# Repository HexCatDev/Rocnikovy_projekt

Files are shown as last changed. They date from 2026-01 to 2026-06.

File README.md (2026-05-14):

# Ročníkový projekt S3E Dobeš Tomáš Digitální hodiny
## Zvláštní poděkování
Zvláště bych chtěl poděkovat panu Miroslavu Máchovi za rady a pomoc při výběru součástek a řešení problémů konstrukčního typu.
A také  panu Jiřímu Vinterovi za rady a kontakty.

## To-do list
- [x] Navrhnout schéma 
- [x] Objednat součástky
- [x] Otestovat na breadboardu
- [x] Navrhnout PCB
- [x] Vyrobit PCB osadit, otestovat

## Princip a popis
Původní myšlenka jak zhotovit tento obvod byla, že by se jednotlivé výstupy na zobrazovače připojily přes posuvné registry, ovšem bylo by jich zapotřebí 6 kousků (HH:mm:ss) převod časového údaje z RTC by bylo zhotoveno přímo v PIC.

Po konzultaci s panem Máchou by bylo lepší Multiplexovat číslice 1:6 tzn. že v jednom okamžiku problikne jeden segment, takto se "probliká" každý segment zvlášť v určité rychlosti(Hz), od určité rychlosti ± 30 Hz se obraz jeví jako spojitý.[1]
### Blokové schéma

<figure>
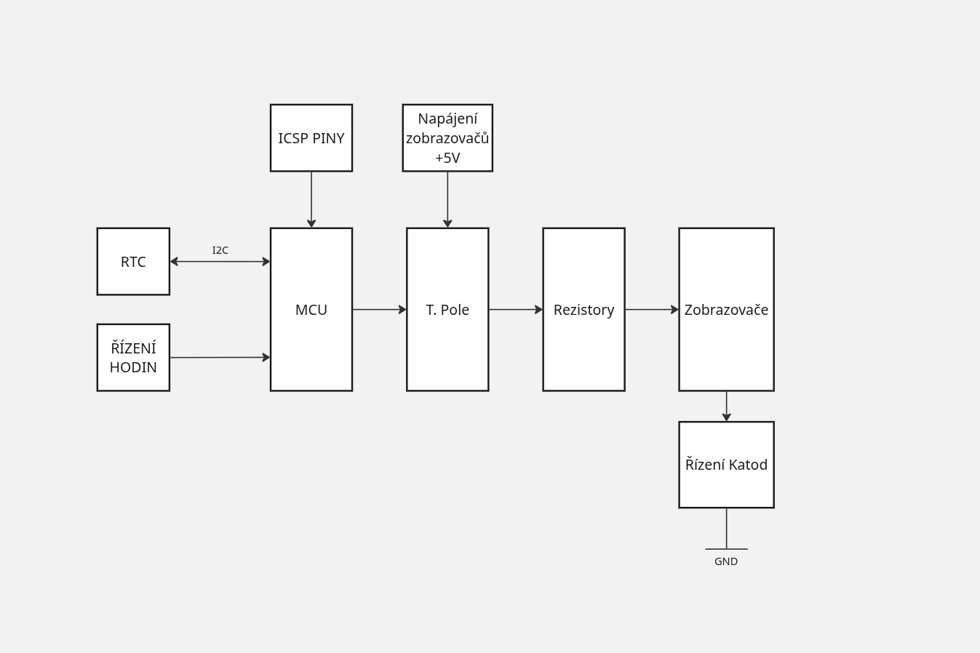
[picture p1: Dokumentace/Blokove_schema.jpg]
Blokové schéma
  
  <figcaption align="center"><i>Obrázek 1: Blokové schéma zapojení hodin</i></figcaption>
</figure>

### Součástky a jejich funkce v obvodu
V této podkapitole budou popsány hlavně podstatné součástky RTC, PIC, tranzistorové pole a samotné tranzistory (touto částí obvodu se chápe zobrazovací část. Vzhledem ke složitosti projektu zde nebude popsáno jak každý samostatný prvek funguje. 

- Obecné informace na vstupu napětí jsou  umístěny tzv. Tank Capacitors[2, kap. 4.2.2], jsou to dva kondenzátory 100uF/35V na napájení jejich funkce zajišťuje stabilní napětí při náhlém zvětšení proudového zatížení. Každý IO napájený z VCC má připojený tzv. Decoupling Capacitors[10] tyto kondenzátory mají na starosti odrušení od možných na indukovaných vysokých frekvencí, všechny mají hodnotu 100nF. Dále je v obvodu implementována dioda která obvod chrání před přepólováním její úbytek je ± 1100mV[11], takže velikost napájecího napětí bude 6V (6-1 = 5V) maximální napětí všech IO je 5,5V. Před vyrobením PCB bude zdroj otestován na stabilitu napětí.

- Mozkem obvodu je PIC18F47Q43-I-P[2] má na starosti komunikaci s RTC, multiplexování a řízení hodin. 

- RTC (Real Time Clock)[3] a Krystal[4] 
Tento IO komunikuje pomocí I2C protokolu s PIC a poskytuje časový údaj tento údaj je poskytován v dekadickém formátu. Má také externí zdroj oscilací krystal o frekvenci 32 768 Hz tato hodnota je definovaná v jeho dokumentaci[3, kap. 4.2.1]. Doporučená hodnota kondenzátorů které slouží jako kapacitní zátěž je 20pF.[3, kap. 4.2.1] Kondenzáty byly zapojeny podle doporučeného zapojení v citaci 3 kapitole FIGURE 4-3[3, kap. FIGURE 4-3].

- Tranzistorové pole ULN2804A[5] tento IO ve svém pouzdře DIP 18 obsahuje 8x NPN transistorů se spol. emitorem s max. kolektorovím  proudem 0,5A a max. napětím mezi kolektorem a emitorem 50V tento IO slouží pro výběr segmentu který bude svítit (A-DP)

- 7 Segmentové zobrazovače[6][7] 2x 20,32mm a 2x 10mm se společnou katodou obsahují 16x znaků v pouzdře 2x8 (7+DP) jsou připojeny na přes rezistory na ULN2804A[5] a jednotlivé znaky jsou připojeny přes tranzistory DTA123JCA[8] které uzemňují daný znak.

- tranzistory IRLML5203 SMD[8] P-MOSFET Uds max. 30V Ic 3A P 1.25W tyto tranzistory zajišťují spojení daného segmentu s napětím VCC tzn. pokud bude na 1. digitu svítit znak "A" ULN2804A[5] přivede na pin A napětí a poté tranzistor sepne a tím přivede na anodu proud poteče přes segmenty které jsou uzemněné a v důsledku toho se rozsvítí.

Video: https://youtu.be/Hi3HrBMFoAA

## Návrh schéma a PCB
- návrh schéma byl konzultován s panem Máchou a také byl upravován v souladu s dokumentací jednotlivých součástek s jejich doporučeními.

<figure>
Schéma strana hlavní
  
  <figcaption align="center"><i>Obr. 1.: Schéma zapojení</i></figcaption>
</figure>

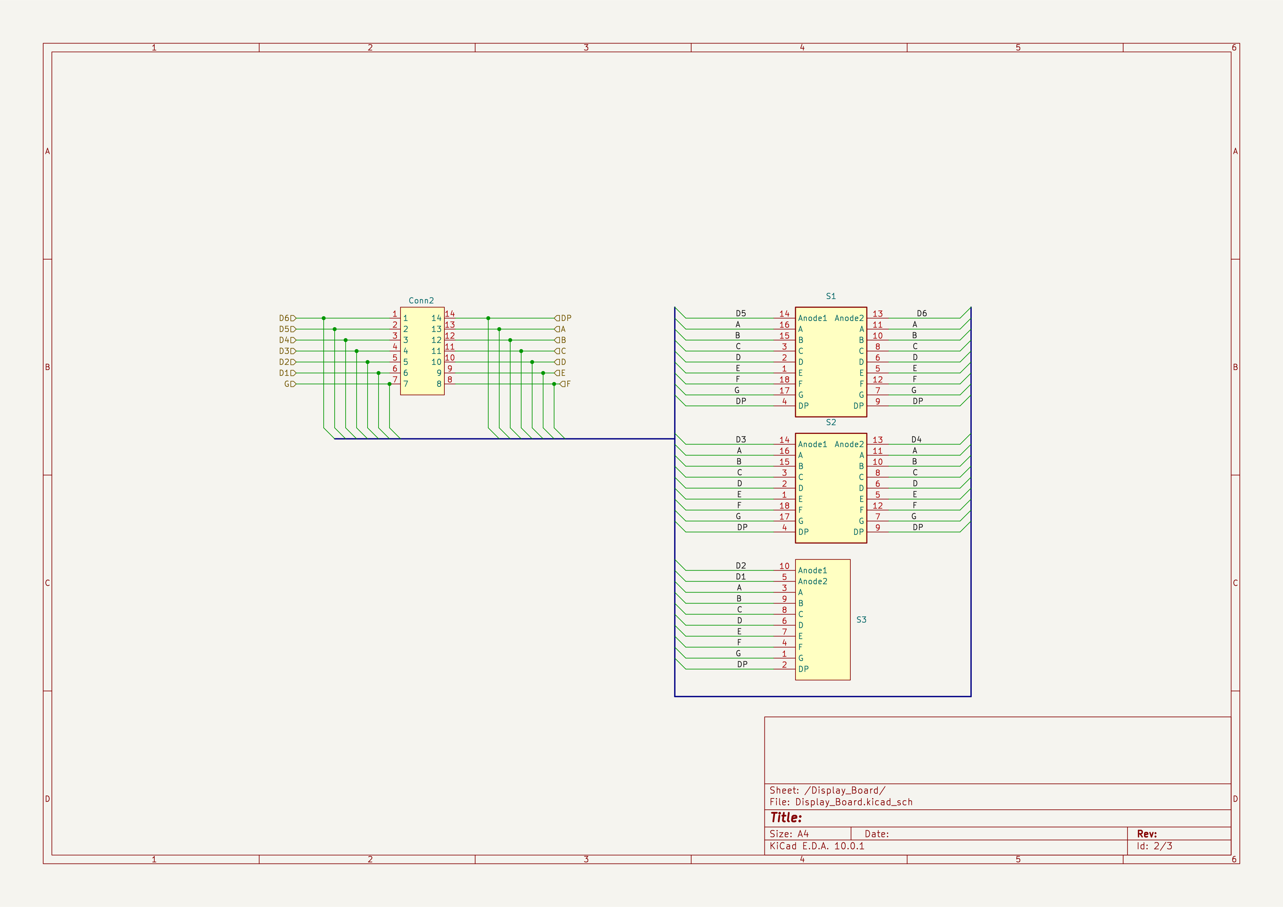
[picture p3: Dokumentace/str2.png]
  
  <figcaption align="center"><i>Obr. 2: Schéma zapojení</i></figcaption>
</figure>

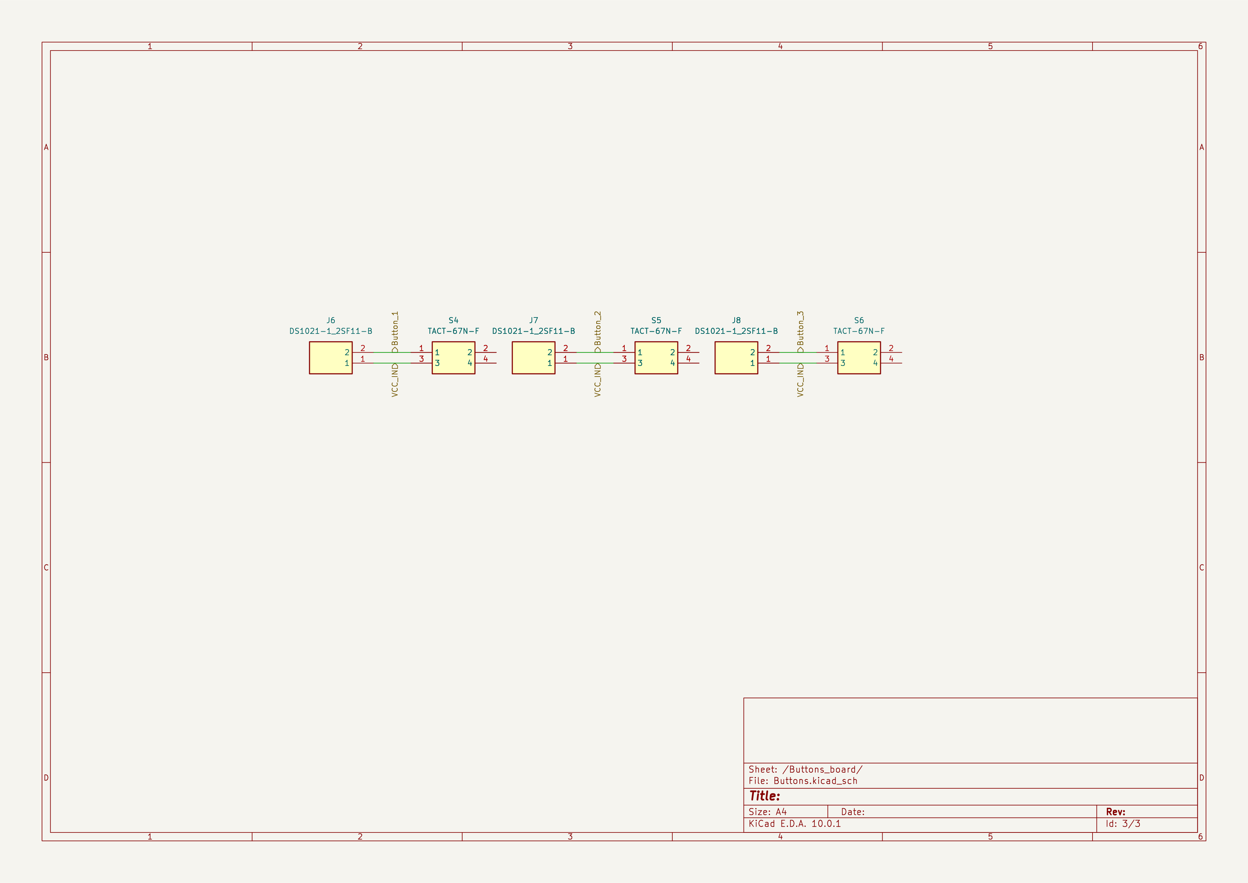
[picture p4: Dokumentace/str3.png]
  
  <figcaption align="center"><i>Obr. 3: Schéma zapojení</i></figcaption>
</figure>

<figure>
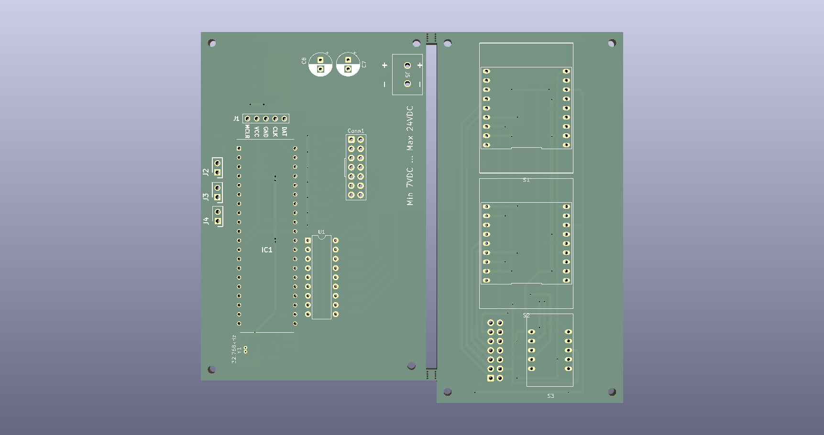
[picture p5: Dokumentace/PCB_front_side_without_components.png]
  
  <figcaption align="center"><i>Obr. 5: Neosazená PCB deska z horní strany strany</i></figcaption>
</figure>

<figure>
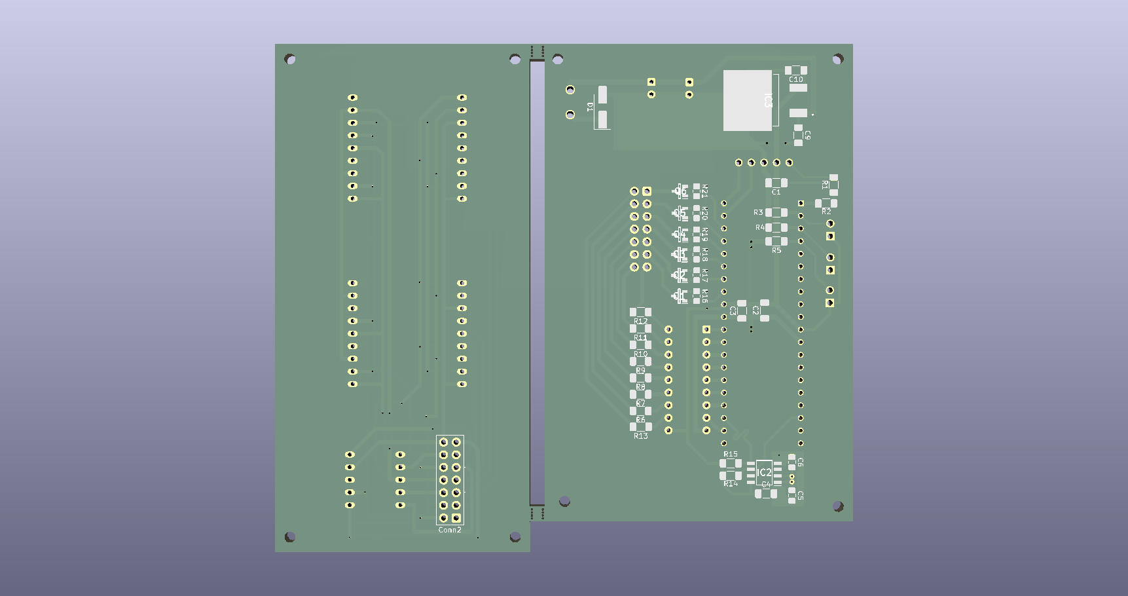
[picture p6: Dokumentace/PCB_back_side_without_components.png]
  
  <figcaption align="center"><i>Obrázek 7: Neosazená PCB deska ze spodní strany</i></figcaption>
</figure>

## Komponenty použité v projektu
- Aktivní součástky
	+ MCU https://ecom.cz/eshop/detail/73426-PIC18F47Q43-I-P
	+ RTC https://ecom.cz/eshop/detail/39997-MCP7940M-I-SN
	+ T. pole https://ecom.cz/eshop/detail/5723-ULN2804A
	+ Tranzistory SMD https://ecom.cz/eshop/detail/80941
	+ Dioda SMD https://ecom.cz/eshop/detail/82063-M7-SMD-T-R
- Krystal
	+ Crystal https://www.tme.eu/cz/details/32.768k-38-sr/krystalove-rezonatory-tht/sr-passives/32-768k-3-8-sr/
- Headry:
	+ 2X https://ecom.cz/eshop/detail/84648
	+ 5X https://ecom.cz/eshop/detail/84654
- Patice
	+ SIL 1X5 https://ecom.cz/eshop/detail/85256
  + SIL 1X9 https://ecom.cz/eshop/detail/85261
  + DIP 18 https://ecom.cz/eshop/detail/64634-DIL-18-3-NT-1
  + DIP 40 https://ecom.cz/eshop/detail/64639-DIL-40-6-YT-1
- Zobrazovače
	+ 7 segment 2X 20,32mm: https://ecom.cz/eshop/detail/29807-LD-FYD-8021DUHR-21
	+ 7 segment 10mm: https://ecom.cz/eshop/detail/29798-LD-FYD-3921BUHR-21
- Pasivní součástky
	+ Rezistory a Kondenzátory
		* 4K7 https://ecom.cz/eshop/detail/71624-R1206-4K7-1--WRX
		* 22 pF https://ecom.cz/eshop/detail/53662
		* 100 nF https://ecom.cz/eshop/detail/21330-C1206-0-1UF-X7R-100V-KNCC
		* 470R https://ecom.cz/eshop/detail/71620-R1206-470R-1--WRX
		* 100uF/35V https://ecom.cz/eshop/detail/78716-CERA-100-35-6-3x11-KM
		* 220R https://ecom.cz/eshop/detail/71588
- Svorkovnice https://ecom.cz/eshop/detail/6649-DG126-5-0-02P-14-02
- Tlačítka https://ecom.cz/eshop/detail/55539-T-0670HIM-160G
- Napájecí vidlice (zásuvka) https://ecom.cz/eshop/detail/78223-KNAPZP-25-1610-01
	+ zástrčka https://ecom.cz/eshop/detail/78201-KNAPVK-2514-NES-J-250
## Použitá literatura

- [1] WIKIPEDIA CONTRIBUTORS. *Flicker fusion threshold*. Wikipedia: The Free Encyclopedia [online]. [cit. 2026-01-02]. Dostupné z: https://en.wikipedia.org/wiki/Flicker_fusion_threshold
- [2] MICROCHIP TECHNOLOGY. *PIC18F27/47/57Q43 Data Sheet: 28/40/44/48-Pin, Low-Power, High-Performance Microcontroller with XLP Technology*. 2021. Dostupné z: https://ecom.cz/data/exportdokumentu?soubor=D73426.pdf&nazev=ECOM_73426_PIC18F47Q43-I-P.pdf 
- [3] MICROCHIP TECHNOLOGY. *MCP7940M: Low-Power I2C Real-Time Clock/Calendar with SRAM*. 2012. Dostupné z: https://ecom.cz/data/exportdokumentu?soubor=D39997.pdf&nazev=ECOM_39997_MCP7940M-I-SN.pdf
- [4] SR PASSIVES. *Crystal 32.768kHz: 32.768K-3/8-SR Specification*. Dostupné z: https://www.tme.eu/Document/4ebb629a31bbf93152d2908870dbe0d1/WX2.pdf
- [5] STMICROELECTRONICS. *ULN2801A, ULN2802A, ULN2803A, ULN2804A: Eight Darlington Transistor Arrays*. 2012. Dostupné z: https://ecom.cz/data/exportdokumentu?soubor=D05723.pdf&nazev=ECOM_05723_ULN2804A.pdf
- [6] FORYARD OPTOELECTRONICS. *FYD-8021DUHR-21: Dual Digit 7-Segment Display Specification*. Dostupné z: https://ecom.cz/data/exportdokumentu?soubor=D29806.pdf&nazev=ECOM_29807_LD-FYD-8021DUHR-21.pdf
- [7] FORYARD OPTOELECTRONICS. *FYD-3921BUHR-21: Single Digit 7-Segment Display Specification*. Dostupné z:https://ecom.cz/data/exportdokumentu?soubor=D29797.pdf&nazev=ECOM_29798_LD-FYD-3921BUHR-21.pdf
- [8] 	IRF - Infineon/International Rectifier. *	Tranzistor MFET-P, Uds=30V, Id=3A, P=1.25W, Ron=165mOhm*. Dostupné z: https://ecom.cz/data/exportdokumentu?soubor=D80941.pdf&nazev=ECOM_80941_IRLML5203-SMD.pdf
- [10] WIKIPEDIA CONTRIBUTORS. *Decoupling*. Wikipedia: The Free Encyclopedia [online]. Dostupné z: https://en.wikipedia.org/wiki/Capacitor#Decoupling
- [11] KOME *M7 SMD T/R* Dostupné z: https://www.tme.eu/Document/4a413fd76a83438d5e8f54eb6b2d20d6/m1.pdf

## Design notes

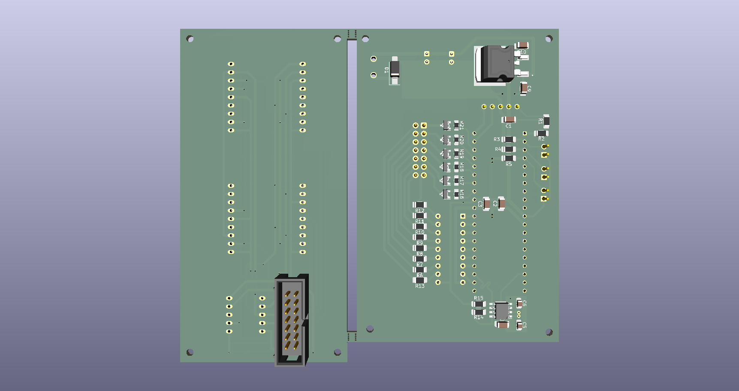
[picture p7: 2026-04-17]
Dokumentace/PCB_back_side.png

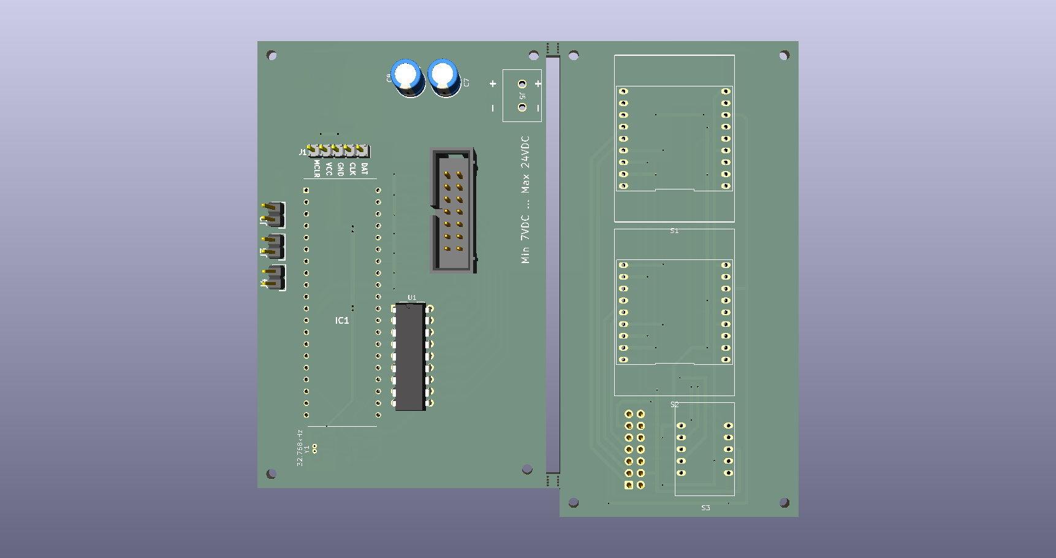
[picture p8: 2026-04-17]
Dokumentace/PCB_front_side.png

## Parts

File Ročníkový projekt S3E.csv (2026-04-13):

Reference | Qty | Value | Footprint
C1,C2 | 2 | 100uF | Capacitor_THT:CP_Radial_D6.3mm_P2.50mm
C3,C4,C5,C6,C7,C10 | 6 | 100nF | Capacitor_SMD:C_1206_3216Metric_Pad1.33x1.80mm_HandSolder
C8,C9 | 2 | 7pF | Capacitor_SMD:C_0805_2012Metric_Pad1.18x1.45mm_HandSolder
Conn1,Conn2 | 2 | ~ | My parts:DIP-14_IDC_2x14
D1 | 1 | M7 SMD T/R | Diode_SMD:D_SMA_Handsoldering
IC1 | 1 | PIC18F47Q43-I_P | My parts:DIP1543W58P254L5175H635Q40N
IC2 | 1 | ULN2804A | My parts:DIP850W46P254L2324H393Q18N
IC3 | 1 | L7805CD2T-TR | My parts:L7805CD2T
IC4 | 1 | MCP7940M-I_SN | SOIC127P600X175-8N
J1 | 1 | DG126-5.0-02P-14-00A | My parts:CONN_DG126-5.0-02P_DEG
J2,J3,J5 | 3 | DS1021-1_2SF11-B | SamacSys_Parts:HDRV2W64P0X254_1X2_508X254X588P
J4 | 1 | TSW-105-07-G-S | My parts:TSW-105-XX-YY-S
J6,J7,J8 | 3 | DS1021-1_2SF11-B | HDRV2W64P0X254_1X2_508X254X588P
Q1,Q2,Q3,Q4,Q5,Q6 | 6 | DTA123JCAT116 | My parts:TRANS_DTA113ZCAH_ROM
R1,R2,R3,R4,R5,R6,R7,R8 | 8 | 330R | Resistor_THT:R_Axial_DIN0309_L9.0mm_D3.2mm_P12.70mm_Horizontal
R9,R11,R12,R13,R14 | 5 | 4K7 | Resistor_SMD:R_1206_3216Metric_Pad1.30x1.75mm_HandSolder
R10 | 1 | 470R | Resistor_SMD:R_1206_3216Metric_Pad1.30x1.75mm_HandSolder
R15 | 1 | 4k7 | Resistor_SMD:R_1206_3216Metric_Pad1.30x1.75mm_HandSolder
S1 | 1 | S,TACT-67N-F | My parts:Patice_display,TACT67NF
S2,S3 | 2 | TACT-67N-F | TACT67NF
Y1 | 1 | 32 768Hz | Crystal:32.768KHz Vertical 3_8mm

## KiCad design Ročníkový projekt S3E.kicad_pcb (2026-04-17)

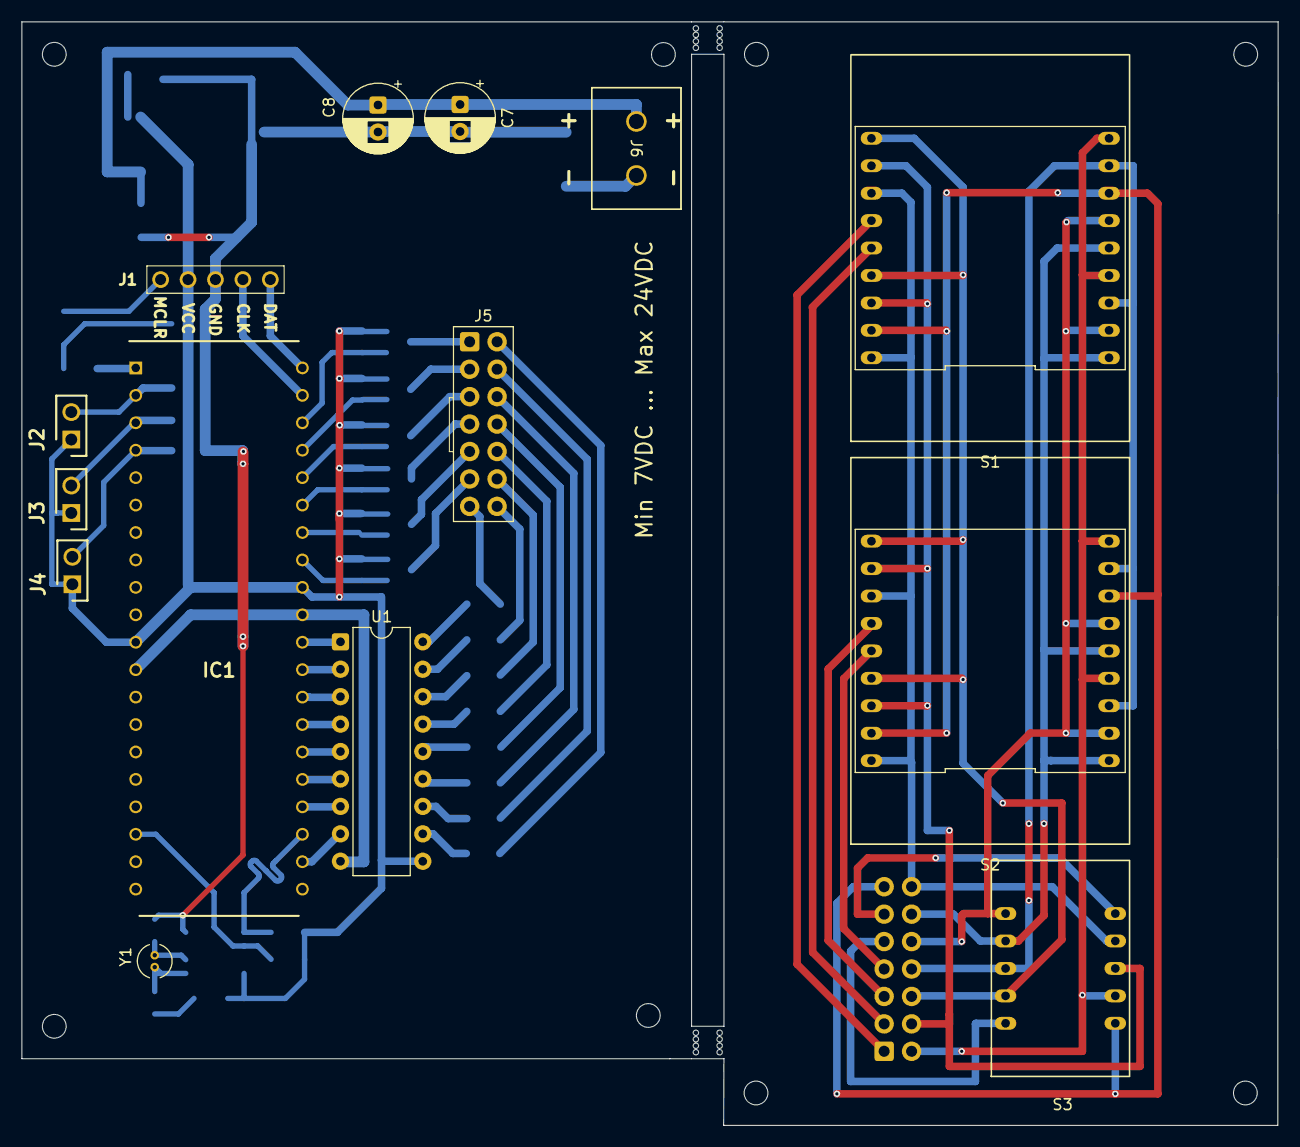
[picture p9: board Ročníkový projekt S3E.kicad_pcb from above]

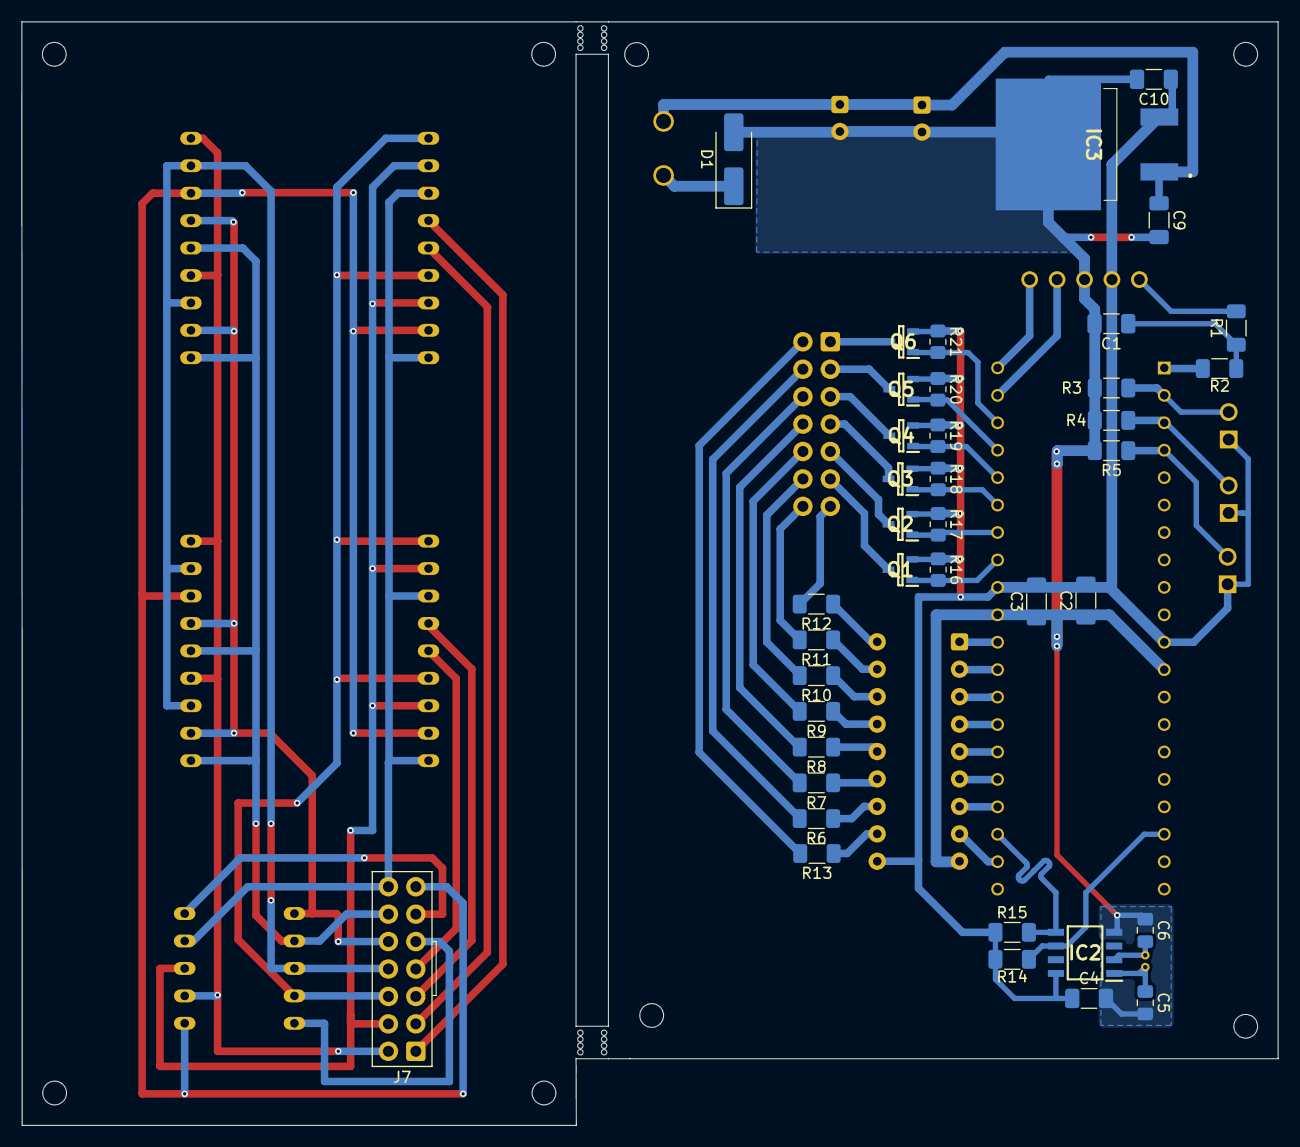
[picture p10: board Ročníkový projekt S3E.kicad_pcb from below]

Board: 2 copper layers, 116.3 x 102.2 mm, 59 parts (39 on the bottom side), 52 nets.

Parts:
C1, C2, C3, C4, C9, C10: 100nF; C_1206_3216Metric_Pad1.33x1.80mm_HandSolder
C5, C6: 6,8pF; C_0805_2012Metric_Pad1.18x1.45mm_HandSolder
C7, C8: 100uF; CP_Radial_D6.3mm_P2.50mm
D1: M7 SMD T/R; D_SMA_Handsoldering
H1, H2, H3, H4, H5, H6: MountingHole_2.2mm_M2
IC1: PIC18F47Q43-I_P; DIP1543W58P254L5175H635Q40N
IC2: MCP7940M-I_SN; SOIC127P600X175-8N
IC3: L7805CD2T-TR; L7805CD2T
J1: TSW-105-07-G-S; TSW-105-XX-YY-S
J2, J3, J4: DS1021-1_2SF11-B; HDRV2W64P0X254_1X2_508X254X588P
J5, J7: DIP-14_IDC_2x14
J6: DG126-5.0-02P-14-00A; CONN_DG126-5.0-02P_DEG
Q1, Q2, Q3, Q4, Q5, Q6: YJL2301D; SOT95P240X115-3N
R1, R3, R4, R5, R14, R15: 4K7; R_1206_3216Metric_Pad1.30x1.75mm_HandSolder
R2: 470R; R_1206_3216Metric_Pad1.30x1.75mm_HandSolder
R6, R7, R8, R9, R10, R11, R12, R13: 220R; R_1206_3216Metric_Pad1.30x1.75mm_HandSolder
R16, R17, R18, R19, R20, R21: 10K; R_0805_2012Metric_Pad1.20x1.40mm_HandSolder
S1, S2: DIP 18 Patice Display Digit 1
S3: DIP-10 Patice Display Digit 3 4
U1: ULN2803A; DIP-18_W7.62mm
Y1: 32 768Hz; Crystal_C38-LF_D3.0mm_L8.0mm_Vertical MY 32kHz

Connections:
/A: R6.1, U1.12 (O7)
/A': J5.13, J7.13, R6.2, S1.11 (A), S1.16 (A), S2.11 (A), S2.16 (A), S3.3 (A)
/B: R7.1, U1.13 (O6)
/B': J5.12, J7.12, R7.2, S1.10 (B), S1.15 (B), S2.10 (B), S2.15 (B), S3.9 (B)
/Buttons_board/Button_1: IC1.2 (RA0), J2.2, R3.1
/Buttons_board/Button_2: IC1.3 (RA1), J3.2, R4.1
/Buttons_board/Button_3: IC1.4 (RA2), J4.2, R5.1
/C: R8.1, U1.14 (O5)
/C': J5.11, J7.11, R8.2, S1.3 (C), S1.8 (C), S2.3 (C), S2.8 (C), S3.8 (C)
/D: R9.1, U1.15 (O4)
/D': J5.10, J7.10, R9.2, S1.2 (D), S1.6 (D), S2.2 (D), S2.6 (D), S3.6 (D)
/DP: R13.1, U1.11 (O8)
/DP': J5.14, J7.14, R13.2, S1.4 (DP), S1.9 (DP), S2.4 (DP), S2.9 (DP), S3.2 (DP)
/Display_Board/D1: J5.6, J7.6, Q1.3 (D), S3.5 (Anode2)
/Display_Board/D2: J5.5, J7.5, Q2.3 (D), S3.10 (Anode1)
/Display_Board/D3: J5.4, J7.4, Q3.3 (D), S2.14 (Anode1)
/Display_Board/D4: J5.3, J7.3, Q4.3 (D), S2.13 (Anode2)
/Display_Board/D5: J5.2, J7.2, Q5.3 (D), S1.14 (Anode1)
/Display_Board/D6: J5.1, J7.1, Q6.3 (D), S1.13 (Anode2)
/E: R10.1, U1.16 (O3)
/E': J5.9, J7.9, R10.2, S1.1 (E), S1.5 (E), S2.1 (E), S2.5 (E), S3.7 (E)
/F: R11.1, U1.17 (O2)
/F': J5.8, J7.8, R11.2, S1.12 (F), S1.18 (F), S2.12 (F), S2.18 (F), S3.4 (F)
/G: R12.1, U1.18 (O1)
/G': J5.7, J7.7, R12.2, S1.7 (G), S1.17 (G), S2.7 (G), S2.17 (G), S3.1 (G)
A_1: IC1.33 (RB0), Q1.1 (G), R16.2
A_2: IC1.34 (RB1), Q2.1 (G), R17.2
A_3: IC1.35 (RB2), Q3.1 (G), R18.2
A_4: IC1.36 (RB3), Q4.1 (G), R19.2
A_5: IC1.37 (RB4), Q5.1 (G), R20.2
A_6: IC1.38 (RB5), Q6.1 (G), R21.2
GND: C1.2, C2.1, C3.1, C4.2, C5.2, C6.1, C7.2, C8.2, C9.2, C10.2, D1.2 (A), IC1.12 (VSS_1), IC1.31 (VSS_2), IC2.4 (VSS), IC3.2 (GND), J1.3, R3.2, R4.2, R5.2, U1.9 (GND)
ICSP_CLK: IC1.39 (RB6/ICSPCLK), J1.4
ICSP_DAT: IC1.40 (RB7/ICSPDAT), J1.5
unnamed: C1.1, R1.1, R2.2
unnamed: D1.1 (K), J6.2
unnamed: IC1.1 (~MCLR/VPP/RE3), R2.1
unnamed: C5.1, IC2.1 (X1), Y1.1
unnamed: C6.2, IC2.2 (X2), Y1.2
unnamed: C7.1, C8.1, C9.1, IC3.1 (INPUT), J6.1
unnamed: J1.1, R1.2
PIC_A: IC1.24 (RC5), U1.7 (I7)
PIC_B: IC1.25 (RC6), U1.6 (I6)
PIC_C: IC1.26 (RC7), U1.5 (I5)
PIC_D: IC1.27 (RD4), U1.4 (I4)
PIC_DP: IC1.22 (RD3), U1.8 (I8)
PIC_E: IC1.28 (RD5), U1.3 (I3)
PIC_F: IC1.29 (RD6), U1.2 (I2)
PIC_G: IC1.30 (RD7), U1.1 (I1)
SCL: IC1.18 (RC3), IC2.6 (SCL), R14.2
SDA: IC1.23 (RC4), IC2.5 (SDA), R15.2
VCC: C2.2, C3.2, C4.1, C10.1, IC1.11 (VDD_1), IC1.32 (VDD_2), IC2.8 (VCC), IC3.3 (OUTPUT), J1.2, J2.1, J3.1, J4.1, Q1.2 (S), Q2.2 (S), Q3.2 (S), Q4.2 (S), Q5.2 (S), Q6.2 (S), R14.1, R15.1, R16.1, R17.1, R18.1, R19.1, R20.1, R21.1, U1.10 (COM)

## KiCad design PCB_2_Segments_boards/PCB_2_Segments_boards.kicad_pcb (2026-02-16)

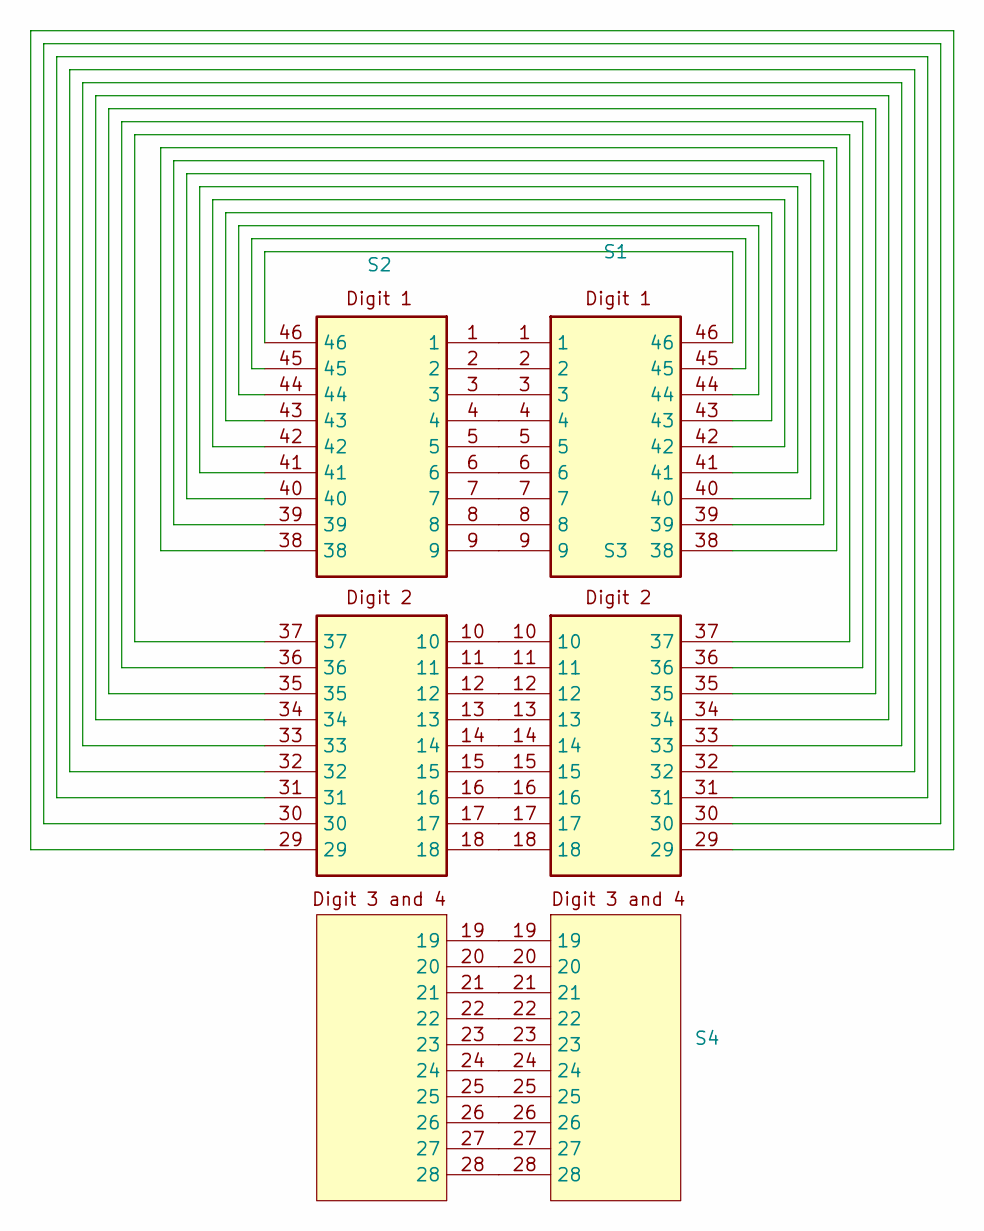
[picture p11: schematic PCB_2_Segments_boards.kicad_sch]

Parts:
S1: DIP 18 Patice Display Digit 1
S2: S; Patice_display
S3: DIP 18 Patice Display Digit 2
S4: DIP-10 Patice Display Digit 3 4

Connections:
unnamed: S1.1, S2.1
unnamed: S1.2, S2.2
unnamed: S1.3, S2.3
unnamed: S1.4, S2.4
unnamed: S1.5, S2.5
unnamed: S1.6, S2.6
unnamed: S1.7, S2.7
unnamed: S1.8, S2.8
unnamed: S1.9, S2.9
unnamed: S1.38, S2.38
unnamed: S1.39, S2.39
unnamed: S1.40, S2.40
unnamed: S1.41, S2.41
unnamed: S1.42, S2.42
unnamed: S1.43, S2.43
unnamed: S1.44, S2.44
unnamed: S1.45, S2.45
unnamed: S1.46, S2.46
unnamed: S2.10, S3.10
unnamed: S2.11, S3.11
unnamed: S2.12, S3.12
unnamed: S2.13, S3.13
unnamed: S2.14, S3.14
unnamed: S2.15, S3.15
unnamed: S2.16, S3.16
unnamed: S2.17, S3.17
unnamed: S2.18, S3.18
unnamed: S2.19, S4.19
unnamed: S2.20, S4.20
unnamed: S2.21, S4.21
unnamed: S2.22, S4.22
unnamed: S2.23, S4.23
unnamed: S2.24, S4.24
unnamed: S2.25, S4.25
unnamed: S2.26, S4.26
unnamed: S2.27, S4.27
unnamed: S2.28, S4.28
unnamed: S2.29, S3.29
unnamed: S2.30, S3.30
unnamed: S2.31, S3.31
unnamed: S2.32, S3.32
unnamed: S2.33, S3.33
unnamed: S2.34, S3.34
unnamed: S2.35, S3.35
unnamed: S2.36, S3.36
unnamed: S2.37, S3.37

Board: 2 copper layers, 4 parts (0 on the bottom side), 46 nets, no tracks yet.

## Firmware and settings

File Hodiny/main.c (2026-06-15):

/**
 * @file main.c
 * @author nontoxiccat
 * @date 2026-01-08
 * @brief 
 */
#include "My_MCC_Config/mcc/mcc_generated_files/system/interrupt.h"
#include <builtins.h>
#include <stdbool.h>
#include <stdint.h>
#include <string.h>
#include <xc.h>
#include <pic18f47q43.h>
// Configuration bits for PIC18F47Q43
#pragma config WDTE = OFF              // Watchdog Timer disabled
#pragma config LVP = ON

#define _XTAL_FREQ 64000000 // Define the operating frequency for delay functions
#define RTC_ADDR 0x6F    // adress 7 bit 110 1111 
#define SEC_REG 0x00        // seconds register
#define MIN_REG 0X01        // minutes register
#define HOUR_REG 0X02       // hours register
#define TL_SET PORTAbits.RA1 // tlačítko pro nastavení pozice
#define TL_ADD PORTAbits.RA2 // tlačítko pro přidání hodin
#define TL_SUB PORTAbits.RA0 // tlačítko pro odečtení hodin

#include "My_MCC_Config/mcc/mcc_generated_files/timer/tmr0.h"
#include "My_MCC_Config/mcc/mcc_generated_files/system/system.h"
#include "My_MCC_Config/mcc/mcc_generated_files/i2c_host/i2c1.h"
#include "clock_config.h" //můj soubor jsou v něm definovány segmenty pro zobrazení číslic a funkce pro zobrazení číslice a nastavení hodin



int main(void)
{ 
    SYSTEM_Initialize();  // this is enough
    pin_init();
    I2C1_Host_CallbackRegister(My_I2C1_Interrupt);
    TMR0_OverflowCallbackRegister(timer);
    TMR0_Start();
    INTCON0bits.GIEH = 1; 
    INTCON0bits.GIEL = 1;

    
    while (1) {
        if (in_setup_mode == 0) {
            if (sys_clock) {
                system_clock();
                sys_clock = false;
            }
            if (RTC_sync) {
                READ_RTC();
                RTC_sync = false;
            }
            if (waiting_for_data && I2C_trasmission_complete) {
                process_data_from_RTC();
                waiting_for_data = false;
            }
        }
        display_controll();
    }
}

void display_digit(const uint8_t *segments){
    // Indexy v poli: 0=DP, 1=G, 2=F, 3=E, 4=D, 5=C, 6=B, 7=A
    LATDbits.LATD3 = segments[0] & 0x1; // DP
    LATDbits.LATD7 = segments[1] & 0x1; // G
    LATDbits.LATD6 = segments[2] & 0x1; // F
    LATDbits.LATD5 = segments[3] & 0x1; // E
    LATDbits.LATD4 = segments[4] & 0x1; // D
    LATCbits.LATC7 = segments[5] & 0x1; // C
    LATCbits.LATC6 = segments[6] & 0x1; // B
    LATCbits.LATC5 = segments[7] & 0x1; // A
}

void clock_init(uint8_t numbers_out[6]) {
    in_setup_mode = 1; // nastaví se, že jsme v režimu nastavení hodin
    int selected_digit = 4;
    int hold_button_time = 0, theshold = 500; // proměnné pro detekci dlouhého stisku tlačítka, threshold je počet 10ms intervalů pro detekci dlouhého stisku
    int timeout = 0; // proměnná pro detekci timeoutu při čekání na dokončení I2C přenosu, aby se zabránilo nekonečnému čekání pokud by došlo k nějaké chybě v komunikaci s RTC
    int threshold = 333;
    while (1) {
        if (TL_SET == 1) {
            hold_button_time++;
            if (hold_button_time > theshold) {
                // tady se odešlou hodnoty z numbers out do RTC přes I2C a zapnase oscilátor
                I2C_trasmission_complete = false; //reset flagu pro indikaci dokončení I2C přenosu, protože jsme právě zahájili nový přenos
                WRITE_RTC(); //tato funkce se bude volat při dlouhém stisku tlačítka pro nastavení hodin a odešle hodnoty z numbers_out do RTC
                while (!I2C_trasmission_complete && timeout < 100) { //čeká se na uvolnění tlačítka nebo dokončení I2C přenosu, aby se zabránilo tomu, že se během přenosu změní nastavené hodnoty nebo se odešle neúplný přenos
                    __delay_ms(10);
                    timeout++;
                    LATB |= 0x3F; //nastaví všechny tranzistory na high takže se vypnou protože PNP display zhasne
                }
            in_setup_mode = 0; // po uvolnění tlačítka se vypne režim nastavení hodin
            __delay_ms(100);
            TMR0_Start(); // znovu se spustí časovač aby se začal aktualizovat čas na displeji
            return; // po uvolnění tlačítka se vrátí do hlavní smyčky a začne zobrazovat čas
            }
        
        }
        else {
            // Ochrana proti zákmitům (debouncing): tlačítko muselo být stisknuto alespoň 15 průchodů (cca 45 ms)
        if (hold_button_time > 15 && hold_button_time < theshold) { 
            selected_digit = (selected_digit + 1) % 6; // přepnutí na další číslici
        }
            hold_button_time = 0; // reset času držení tlačítka
        }

        if (TL_SUB == 1) {
            switch (selected_digit) {
                case 0: numbers_out[0] = (numbers_out[0] >= 2) ? 0 : numbers_out[0] + 1; break; //hh 0,1,2
                case 1: numbers_out[1] = (numbers_out[1] >= 9) ? 0 : numbers_out[1] + 1; break; //h 0-9
                case 2: numbers_out[2] = (numbers_out[2] >= 5) ? 0 : numbers_out[2] + 1; break; //mm 0-5
                case 3: numbers_out[3] = (numbers_out[3] >= 9) ? 0 : numbers_out[3] + 1; break; //m 0-9
                case 4: numbers_out[4] = (numbers_out[4] >= 5) ? 0 : numbers_out[4] + 1; break; //ss 0-6
                case 5: numbers_out[5] = (numbers_out[5] >= 9) ? 0 : numbers_out[5] + 1; break; //s 0-9
            }
            for (int d = 0; d < 100; d++) {
                refresh_setup_display(selected_digit, numbers_out);
            }
        }

        if (TL_ADD == 1) {
            switch (selected_digit) {
                //tady jsem použil ternary operace tj. (kondice) ? (je pravda) : (není pravda) protože když odečítám 1 od 0, chci aby se číslo změnilo na maximum (např. pro minuty když je 00 a odečtu 1, chci aby se změnilo na 59)
                case 0: numbers_out[0] = (numbers_out[0] -1 ) < 0 ? 2 : numbers_out[0] - 1; break; //hh 0,1,2
                case 1: numbers_out[1] = (numbers_out[1] -1 ) < 0 ? 9 : numbers_out[1] - 1; break; //h 0-9
                case 2: numbers_out[2] = (numbers_out[2] -1 ) < 0 ? 5 : numbers_out[2] - 1; break; //mm 0-5
                case 3: numbers_out[3] = (numbers_out[3] -1 ) < 0 ? 9 : numbers_out[3] - 1; break; //m 0-9
                case 4: numbers_out[4] = (numbers_out[4] -1 ) < 0 ? 5 : numbers_out[4] - 1; break; //ss 0-6
                case 5: numbers_out[5] = (numbers_out[5] -1 ) < 0 ? 9 : numbers_out[5] - 1; break; //s 0-9
            }
            for (int d = 0; d < 100; d++) {
                refresh_setup_display(selected_digit, numbers_out);
            }
        }

        if (numbers_out[0] == 2 && numbers_out[1] >= 4) { // pokud jsou hodiny nastaveny na 24 nebo více, resetuje se na 00
            numbers_out[0] = 0;
            numbers_out[1] = 0;
        }
        refresh_setup_display(selected_digit, numbers_out);
    }
}

void refresh_setup_display(int selected_digit, uint8_t numbers_out[6]) {
    for (int i = 0; i < 6; i++) {
        LATB |= 0x3F; // vypnutí všech tranzistorů (PNP displej zhasne)

        // Pokud index odpovídá vybrané pozici (selected_digit), použijeme znak s tečkou, jinak běžný znak
        const uint8_t *current_segments = (i == selected_digit) ? numbers_DP[numbers_out[i]] : numbers[numbers_out[i]];

        // Spínání tranzistorů podle aktuálního indexu 'i'
        switch (i) {
            case 0: display_digit(current_segments); LATBbits.LATB2 = 0; __delay_us(500); break; 
            case 1: display_digit(current_segments); LATBbits.LATB3 = 0; __delay_us(500); break; 
            case 2: display_digit(current_segments); LATBbits.LATB4 = 0; __delay_us(500); break; 
            case 3: display_digit(current_segments); LATBbits.LATB5 = 0; __delay_us(500); break; 
            case 4: display_digit(current_segments); LATBbits.LATB1 = 0; __delay_us(500); break; 
            case 5: display_digit(current_segments); LATBbits.LATB0 = 0; __delay_us(500); break; 
            default: break;
        }
    }
}

void display_controll(){
    if (TL_SET == 1) {
        TMR0_Stop(); //zastaví časovač aby se zabránilo konfliktu mezi timerem a zobrazením číslic při nastavení hodin
        ms_sync_counter = 0; //resetuje se čítač pro synchronizaci s RTC aby se zabránilo tomu, že se během nastavení hodin synchronizuje čas s RTC a změní se nám nastavené hodnoty
        ms_counter = 0; //resetuje se čítač pro synchronizaci s RTC aby se zabránilo tomu, že se během nastavení hodin synchronizuje čas s RTC a změní se nám nastavené hodnoty
        LATB |= 0x3F; //zhasne nám display
        __delay_ms(100);
        clock_init(numbers_out);
        __delay_ms(100);
    }

    for (int i = 0; i < 6; i++) {
        // toto je bitwisová operace OR pro nastavení bitů 0-5 na 1, což znamená, že všechny tranzistory jsou vypnuté (protože jsou PNP)
        LATB |= 0x3F;
        // nastaví určitý tranzistor na low takže se zapne
        switch (i) {
            case 0: display_digit(numbers[numbers_out[0]]); LATBbits.LATB2 = 0; __delay_us(500); break;
            case 1: display_digit(numbers[numbers_out[1]]); LATBbits.LATB3 = 0; __delay_us(500); break; 
            case 2: display_digit(numbers[numbers_out[2]]); LATBbits.LATB4 = 0; __delay_us(500); break; 
            case 3: display_digit(numbers[numbers_out[3]]); LATBbits.LATB5 = 0; __delay_us(500); break; 
            case 4: display_digit(numbers[numbers_out[4]]); LATBbits.LATB1 = 0; __delay_us(500); break; //s
            case 5: display_digit(numbers[numbers_out[5]]); LATBbits.LATB0 = 0; __delay_us(500); break; //ss
        }
    }
}

void READ_RTC(void) {
    waiting_for_data = true;
    I2C_trasmission_complete = false;
    static uint8_t reg_addr = SEC_REG;
    I2C1_Host_WriteRead(RTC_ADDR, &reg_addr, 1, bcd_numbers_recieved, 3); // "Host" prefix
}

void WRITE_RTC(){//tato funkce se bude volat při dlouhém stisku tlačítka pro nastavení hodin a odešle hodnoty z numbers_out do RTC

    payload[0] = SEC_REG; // adresa registru pro sekundy
    payload[1] = time_to_BCD(numbers_out[4], numbers_out[5]);
    payload[1] = payload[1] | 0x80; // bitwisový operátor OR (|) také funguje jako přenastavitel bitů nechá všechny bity stejné kromě bitu 7 který nastaví na 1 což zapne oscilátor v RTC
    payload[2] = time_to_BCD(numbers_out[2], numbers_out[3]); // hodnota pro minuty v BCD formátu
    payload[3] = time_to_BCD(numbers_out[0], numbers_out[1]); // hodnota pro hodiny v BCD formátu

    I2C_trasmission_complete = false;
    I2C1_Host_Write(RTC_ADDR, payload, 4); // odešle data do RTC, první byte je adresa registru pro sekundy a další 3 byty jsou hodnoty pro sekundy, minuty a hodiny v BCD formátu
}

void system_clock(){ //tato funkce se bude volat každou sekundu a bude aktualizovat čas na displeji a je založena na funkci timer()
    numbers_out[5]++; 
    if (numbers_out[5] >= 10) { 
        numbers_out[5] = 0;
        numbers_out[4]++;
        if (numbers_out[4] >= 6){ 
            numbers_out[4] = 0;
            numbers_out[3]++;
            if (numbers_out[3] >= 10){
                numbers_out[3] = 0;
                numbers_out[2]++;
                if (numbers_out[2] >= 6){ 
                    numbers_out[2] = 0;
                    numbers_out[1]++;
                    if (numbers_out[0] == 2 && numbers_out[1] >= 4) { 
                        memset(numbers_out, 0, sizeof(numbers_out));
                    } else if (numbers_out[1] >= 10) {
                        numbers_out[1] = 0;
                        numbers_out[0]++;
                    }
                }
            }
        }
    }
}

void timer(void){
    ms_sync_counter++; //inkrementace čítače pro měření času v milisekundách
    ms_counter++; //inkrementace čítače pro měření času v milisekundách
    if (ms_counter >= 997 && in_setup_mode == 0) { //když uplyne 1 sekunda
        sys_clock = true; //nastaví se flag pro sys clock
        ms_counter = 0;
    }
    if (in_setup_mode == 0) {
        if (ms_sync_counter >= 900000UL) { //když uplyne 15 minut, synchronizuje se čas s RTC
            RTC_sync = true; //nastaví se flag pro RTC sync
            ms_sync_counter = 0;
        }
    }
}

void My_I2C1_Interrupt(void){ // toto je callback funkce pro dokončení I2C přenosu, která se volá, když je I2C přenos dokončen
    I2C_trasmission_complete = true; //nastaví se flag pro indikaci dokončení I2C přenosu
}

void process_data_from_RTC(){ //tato funkce se bude volat, když je dokončen I2C přenos a aktualizuje čas na displeji podle dat z RTC
    bcd_numbers_recieved[0] = bcd_numbers_recieved[0] & 0x7F; //bitwisový operátor AND (&) nechá všechny bity stejné kromě bitu 7 který nastaví na 0 protože bit 7 v registru pro sekundy je pro oscilátor a nechceme ho zobrazovat na displeji
    numbers_out[4] = bcd_numbers_recieved[0] >> 4; //vyextrahuje desítky sekund z BCD hodnoty
    numbers_out[5] = bcd_numbers_recieved[0] & 0x0F; //vyextrahuje jednotky sekund z BCD hodnoty

    numbers_out[2] = bcd_numbers_recieved[1] >> 4; //vyextrahuje desítky minut z BCD hodnoty
    numbers_out[3] = bcd_numbers_recieved[1] & 0x0F; //vyextrahuje jednotky minut z BCD hodnoty
    
    bcd_numbers_recieved[2] = bcd_numbers_recieved[2] & 0x3F; //bitwisový operátor AND (&) nechá všechny bity stejné kromě bitů 6 a 7 které nastaví na 0 protože bity 6 a 7 v registru pro hodiny jsou pro 12/24 hodinový režim a AM/PM a nechceme je zobrazovat na displeji
    numbers_out[0] = bcd_numbers_recieved[2] >> 4; //vyextrahuje desítky hodin z BCD hodnoty
    numbers_out[1] = bcd_numbers_recieved[2] & 0x0F; //vyextrahuje jednotky hodin z BCD hodnoty
}

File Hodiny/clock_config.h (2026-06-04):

#ifndef CLOCK_CONFIG_H
#define CLOCK_CONFIG_H
#define _XTAL_FREQ 64000000 //definice frekvence pro delay funkce

#include <language_support.h>
#include <pic18f47q43.h>
#include <stdint.h>
#include <xc.h> 
#include <stdbool.h>

#define G = TRISDbits.TRISD7 = 0; //G
#define F = TRISDbits.TRISD6 = 0; //F
#define E = TRISDbits.TRISD5 = 0; //E
#define D = TRISDbits.TRISD4 = 0; //D
#define DP = TRISDbits.TRISD3 = 0; //DP
#define C = TRISCbits.TRISC7 = 0; //C
#define B = TRISCbits.TRISC6 = 0; //B
#define A = TRISCbits.TRISC5 = 0; //A

#define time_to_BCD(tens, ones) ( (uint8_t) ((tens) << 4) | (ones)) //toto je makro vloží se do něj dvě hodnoty desítky a jednotky a ono vrátí hodnotu
// v BCD formátu tj. pro třeba 45 sec máme 4 a 5, tens 4 ones 5 makro vezme 4 převede ho do binárního formátu což je 0100 a posune ji 
// o 4 bity doleva (<< 4) takže vznikne 0100 0000 pak je tu bitwise OR (|) což slepí dvě hodnoty doromady, 5 je v bin 0101 (4+1)
// výsledkem slepení je 0100 0101 což je 0x45 v hexu a to je BCD reprezentace čísla 45.
// takže tady to bude bcd_numbers[3] = {time_to_BCD(numbers_out[4], numbers_out[5])}
// do hodnoty 3 v poli bcd_numbers se uloží převod hodnot z numbers_out[4] a numbers_out[5] do BCD formátu což jsou sekundy
// to se pak jako celek pošle do RTC


// Forward declarations
void READ_RTC(void);
void WRITE_RTC(void);
void system_clock(void);
void timer(void);
void display_controll(void);
void My_I2C1_Interrupt(void);
void process_data_from_RTC(void);
void refresh_setup_display(int selected_digit, uint8_t numbers_out[6]);

const uint8_t numbers[10][8] = {
    {0, 0, 1, 1, 1, 1, 1, 1}, //0
    {0, 0, 0, 0, 0, 1, 1, 0}, //1
    {0, 1, 0, 1, 1, 0, 1, 1}, //2
    {0, 1, 0, 0, 1, 1, 1, 1}, //3
    {0, 1, 1, 0, 0, 1, 1, 0}, //4
    {0, 1, 1, 0, 1, 1, 0, 1}, //5
    {0, 1, 1, 1, 1, 1, 0, 1}, //6
    {0, 0, 0, 0, 0, 1, 1, 1}, //7
    {0, 1, 1, 1, 1, 1, 1, 1}, //8
    {0, 1, 1, 0, 1, 1, 1, 1} //9
};      // DP,    G,      F,    E,      D,    C,     B,     A

const uint8_t numbers_DP[10][8] = {
    {1, 0, 1, 1, 1, 1, 1, 1}, //0
    {1, 0, 0, 0, 0, 1, 1, 0}, //1
    {1, 1, 0, 1, 1, 0, 1, 1}, //2
    {1, 1, 0, 0, 1, 1, 1, 1}, //3
    {1, 1, 1, 0, 0, 1, 1, 0}, //4
    {1, 1, 1, 0, 1, 1, 0, 1}, //5
    {1, 1, 1, 1, 1, 1, 0, 1}, //6
    {1, 0, 0, 0, 0, 1, 1, 1}, //7
    {1, 1, 1, 1, 1, 1, 1, 1}, //8
    {1, 1, 1, 0, 1, 1, 1, 1} //9
};      // DP,    G,      F,    E,      D,    C,     B,     A

static inline void pin_init() { //nastavení pinů jako výstupy a vstupy
    // I2C vyžaduje Open-Drain konfiguraci pro piny RC3 a RC4
    ODCONCbits.ODCC3 = 1;
    ODCONCbits.ODCC4 = 1;

    // Konfigurace specifických I2C úrovní (Slew rate a SMBus/I2C thresholds)
    RC3I2C = 0x01; // SCL 
    RC4I2C = 0x01; // SDA

    // všechny piny na Digital
    ANSELA = 0x00;
    ANSELB = 0x00;
    ANSELC = 0x00;
    ANSELD = 0x00; 

    // Nastavení I2C pinů jako VSTUPY podle dokumentace k I2C modulu
    TRISCbits.TRISC3 = 1; // SCL jako vstup
    TRISCbits.TRISC4 = 1; // SDA jako vstup

    TRISB &= ~0x3F; //nastavení výstupů pro B0-B5 transzistory PNP bitwisová operace AND s negací 0x3F (0011 1111) nastaví bity 0-5 na 0 (výstup) a zbytek ponechá beze změny

    // Tyto hodnoty reprezentují segmenty A_DP
    TRISDbits.TRISD7 = 0; //G
    TRISDbits.TRISD6 = 0; //F
    TRISDbits.TRISD5 = 0; //E
    TRISDbits.TRISD4 = 0; //D
    TRISDbits.TRISD3 = 0; //DP
    TRISCbits.TRISC7 = 0; //C
    TRISCbits.TRISC6 = 0; //B
    TRISCbits.TRISC5 = 0; //A
    

    //nastavení vstupů pro tlačítka
    TRISAbits.TRISA1 = 1; // hodiny zpět 
    TRISAbits.TRISA0 = 1; // výběr pozice
    TRISAbits.TRISA2 = 1; // hodiny vpřed

    INTCON0bits.IPEN = 1; // povolení priorit přerušení
    INTCON0bits.GIEH = 1; // povolení globálních přerušení s vysokou prioritou
    INTCON0bits.GIEL = 1; // povolení globálních přerušení s nízkou prioritou
}

enum Segments { DPS, As, BS, CS, DS, ES, FS, GS };

uint8_t numbers_out[6] = {0, 0, 0, 0, 0, 0}; // pole pro uchování aktuálních čísel na displeji
uint8_t in_setup_mode = 0; // proměnná pro indikaci, zda jsme v režimu nastavení hodin
uint8_t bcd_numbers[4] = {0, 0, 0}; // pole pro uchování hodnot v BCD formátu pro hodiny, minuty a sekundy
uint8_t payload[4] = {0, 0, 0, 0}; // pole pro uchování dat pro I2C komunikaci s RTC
uint8_t bcd_numbers_recieved[3] = {0, 0, 0,}; // pole pro uchování dat přijatých z RTC
volatile uint32_t ms_sync_counter = 0; // čítač pro měření času v milisekundách, inkrementuje se v přerušení od časovače
volatile uint16_t ms_counter = 0; // čítač pro měření času v milisekundách, inkrementuje se v přerušení od časovače


volatile bool I2C_trasmission_complete = false; // flag pro indikaci dokončení I2C přenosu
volatile bool sys_clock = false; // flag pro sys clock
volatile bool RTC_sync = false; // flag pro RTC sync
static bool waiting_for_data = false; // flag pro čekání na data z RTC
#endif

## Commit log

2026-01-02 Move project files to root and add KiCad project
    [Ročníkový projekt S3E.kicad_pcb, Ročníkový projekt S3E.kicad_sch]
2026-01-06 backup update
    [Ročníkový projekt S3E.kicad_pcb, Ročníkový projekt S3E.kicad_sch]
2026-04-13 Auto-backup: 21:43:30 13/04/2026
    [Buttons.kicad_sch, Ročníkový projekt S3E.csv, Ročníkový projekt S3E.kicad_sch]
2026-04-15 Auto-backup: 09:05:42 15/04/2026
    [Buttons.kicad_sch, Display_Board.kicad_sch, Ročníkový projekt S3E.kicad_pcb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]
2026-04-15 Ignore KiCad local history snapshots
2026-04-17 Auto-backup: 10:53:27 17/04/2026
    [Buttons.kicad_sch, Display_Board.kicad_sch, Ročníkový projekt S3E.kicad_pcb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]
2026-04-17 Auto-backup: 15:10:38 17/04/2026
    [Ročníkový projekt S3E.kicad_pcb, Ročníkový projekt S3E.kicad_sch]
2026-04-17 Auto-backup: 18:09:10 17/04/2026
    [Buttons.kicad_sch, Display_Board.kicad_sch, Ročníkový projekt S3E.kicad_pcb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]
2026-05-04 Auto-backup: 00:14:14 05/05/2026
    [Ročníkový projekt S3E.kicad_sch]
2026-05-14 Auto-backup: 07:48:27 14/05/2026
    [Ročníkový projekt S3E.kicad_sch]
